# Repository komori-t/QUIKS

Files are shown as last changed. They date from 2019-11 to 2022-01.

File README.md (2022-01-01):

# QUIKS


QUIKS unifies inexpensive kinetic sensors

## About

QUIKS is an inexpensive motion tracking system.

It is consists of one terminal node and multiple sensor nodes.

Each node has a sensor and the terminal node bridges PC and them.



## QUIKS is ...

### 1. Inexpensive

QUIKS is designed to construct motion tracking system at low cost.

### 2. Extendable

New node can be added by just connecting to RS485 bus.

It is easy to develop new kind of node to extend the system.

### 3. Scalable

More nodes you connect, more data you get.

So you can omit any nodes to reduce costs, areas, times, etc.

If you do not need to track the lower half of your body, you can only upper half nodes for example.

## Currently available node

### IMUTracker

The IMUTracker is a kind of node that captures rotation of one bone.

It has IMU sensor ICM20948 controlled by a tiny microcontroller LPC802.

### USB terminal node

USB terminal node is a kind of terminal node that communicates with PC through USB.

It acts as virtual serial port and bridges USB and RS485 bus.

IMUTracker and USB terminal node shares the same design of circuit to reduce manufacturing costs.

## Other nodes to be added (hopefully)

### Wireless terminal node

Wireless terminal node is a kind of teminal node that communicates with PC wirelessly (maybe in 900 MHz band).

### Absolute position tracking node

If the position of one bone (typically waist) can be detected, it is possible to move around in virtual world.

## Documentation

A technical memo (in the form of paper) of IMUTracker can be found [here](https://gist.github.com/komori-t/2a9c5ed3c2d6123b80474edbda02dfcf/raw/6774a583ee427da89996ef7d9e91693c2fbc6523/imutracker.pdf).

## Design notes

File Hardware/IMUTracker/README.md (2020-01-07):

# IMUTracker
hardware_abst_image

## Design and connectivity
IMUTracker system is consisted of two different designs, Base and Single. Both uses same IMUTracker sensor on it, also Base uses MicroUSB to RS485 convertor as well. The Base have micro usb port, and entire QUIKS will be connected to PC through this port.

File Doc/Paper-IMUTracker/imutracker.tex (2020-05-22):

%! TEX program = pdflatex
\documentclass[journal]{IEEEtran}
\usepackage{siunitx}
\usepackage{amsmath}
\usepackage{amssymb}
\usepackage{bm}
\usepackage[table,xcdraw]{xcolor}
\usepackage[pdftex]{graphicx}

\DeclareGraphicsRule{.ai}{pdf}{.ai}{}

\begin{document}

\title{QUIKS: an inexpensive motion tracking system}
\author{}
\maketitle
\begin{abstract}
Reducing cost for motion tracking system is essential for better virtual reality (VR) experience.
In this paper, we describe our low-cost system named QUIKS.
It is optimized for VR usage only.
Therefore, it can be constructed of inexpensive parts such as IMU and Cortex-M0+ MCU.
In addition, sensors not only sample motions but also calculate offset and apply transformation.
This lowers CPU usage of host PC.
We only spent about 10 dollars for tracking one joint.
In out tests, laptop PC without GPU can perform motion traccking and 3DCG rendering for 30 fps.
The quality and latency of motion is sufficient for VR experience.
\end{abstract}

\section{Introduction}
To capture the movement of a user is essential for the virtual reality (VR) experience.
With the increase of the number of VR user (including game player, streamer, etc.), perchasing motion tracking devices such as Vive tracker or Perception Neuron is thought to be a common case.
However, these products are still expensive and only a few user can perchase them.
Thus, a low-cost motion tracking system which is suitable for VR usage is needed.
Such a device should not track a motion much precisely or quickly.
That is, it is not suitable for the tasks like measurements and only produce 30 or 60 samples per second.
Also, it cannot be used with some particular motions which are difficult to track.

\section{Basis of motion tracking}
\subsection{Target software}
A motion data measured by a sensor is sent to some software to produce CG images for a user.
In this paper, we target Unity for that role because we can use it for free with few limitations.
However, most of our system can be reused for other software.

\subsection{Tracking method}
There are roughly two methods to track motions.
One is an optical method.
It can track almost every motions very precisely with low latency.
However, it needs multiple cameras and lots of calculation resources.
Thus, this method is not suitable for an inexpensive system.

The another is an inertial method.
It cannot track the absolute position of a body, but it is simple and costs less.
Therefore, we adopt this method.

The inertial method captures joint rotations and just assign them to a 3D model.
3DCG engine like Unity manages its internal model movements by rotations.
In general, inertial motion tracking can be achieved with following steps.
\begin{enumerate}
    \item Measure joint rotations by inertial measurement unit(IMU).
    \item Convert measured data for a 3DCG software.
    \item Assign joint rotations to a 3D model.
\end{enumerate}

\subsection{Quaternion}
A rotation in 3D space can be represented as the form of quaternion.
In this paper, we define a quaternion \(\bm{q}\) as (\ref{quat-def}).
\begin{equation}
    \bm{q} \overset{\mathrm{def}}{=} w + \mathbf{i}x + \mathbf{j}y + \mathbf{k}z = w + \begin{pmatrix}
        x \\
        y \\
        z
    \end{pmatrix} \label{quat-def}
\end{equation}
where \(w\) is the real part of a quaternion and \(x,\,y,\,z\) are the imaginary part.
\begin{table}[tb]
    \centering
    \caption{Quaternion multiplication} \label{quat-mult}
    \begin{tabular}{ccccc}
    \rowcolor[HTML]{9B9B9B} 
                                           & 1              & \(\mathbf{i}\)  & \(\mathbf{j}\)  & \(\mathbf{k}\)  \\
    \cellcolor[HTML]{9B9B9B}1              & \(1\)          & \(\mathbf{i}\)  & \(\mathbf{j}\)  & \(\mathbf{k}\)  \\
    \rowcolor[HTML]{EFEFEF} 
    \cellcolor[HTML]{9B9B9B}\(\mathbf{i}\) & \(\mathbf{i}\) & \(-1\)          & \(\mathbf{k}\)  & \(-\mathbf{j}\) \\
    \cellcolor[HTML]{9B9B9B}\(\mathbf{j}\) & \(\mathbf{j}\) & -\(\mathbf{k}\) & \(-1\)          & \(\mathbf{i}\)  \\
    \rowcolor[HTML]{EFEFEF} 
    \cellcolor[HTML]{9B9B9B}\(\mathbf{k}\) & \(\mathbf{k}\) & \(\mathbf{j}\)  & \(-\mathbf{i}\) & \(-1\)         
    \end{tabular}
\end{table}
Multiplication between each parts are defined as Table \ref{quat-mult}.
Also, (\ref{quat-norm}) always have to be valid.
When a quaternion holds this condition, it is called to be normalized.
\begin{equation}
    |\bm{q}| \overset{\mathrm{def}}{=} \sqrt{w^2 + x^2 + y^2 + z^2} = 1 \label{quat-norm} 
\end{equation}
Sometimes we need the inverse (or complementary) quaternion \(\bm{q}^{-1}\) defined as (\ref{quat-inv})
\begin{equation}
    \bm{q}^{-1} \overset{\mathrm{def}}{=} \frac{w - \mathbf{i}x - \mathbf{j}y - \mathbf{k}z}{w^2 + x^2 + y^2 + z^2} = w - \mathbf{i}x - \mathbf{j}y - \mathbf{k}z \label{quat-inv}
\end{equation}

The rotation around the axis \(\bm{u} = (u_x,\,u_y,\,u_z)^\mathrm{T}\in\mathbb{R}^3\) by angle \(\theta\) can be expressed in (\ref{quat-rot}).
\begin{equation}
    \bm{q} = \cos\left(\frac{\theta}{2}\right) + \begin{pmatrix}
        u_x \\
        u_y \\
        u_z
    \end{pmatrix} \sin\left(\frac{\theta}{2}\right) \label{quat-rot}
\end{equation}
where \(|\bm{u}| = 1\).

The rotaion \(\bm{q}_2\bm{q}_1\) means the rotation applying \(\bm{q}_1\), then \(\bm{q}_2\).

Real world coordinate and 3DCG engine coordinate are often different.
Real world is represented as left-handed coordinate system and Unity uses right-handed one for example.
In this case, we should convert rotation axis \(\bm{u}\) to \(\bm{u}'\) with \(\bm{u}' = A\bm{u}\) where \(A\in\mathbb{R}^{3\times 3}\) is an transformation matrix.
Therefore, a quaternion \(\bm{q}\) can be converted to \(\bm{q}'\) by (\ref{quat-conv}).
\begin{equation}
    \bm{q}' = w + A\begin{pmatrix}
        x \\
        y \\
        z
    \end{pmatrix} \label{quat-conv}
\end{equation}

\section{Our system}
\subsection{Overview}
Figure \ref{block} shows the block diagram of our system, QUIKS.
\begin{figure}[tb]
    \centering
    
    \caption{Block diagram of QUIKS} \label{block}
\end{figure}
QUIKS is consists of multiple sensor nodes and a terminal node.
Each sensor node have an IMU and measures rotation of a joint.
The terminal node bridges PC and sensor nodes by converting USB and RS485 communication.
Basically, PC sends requests to each node and sensors return quaternions.
Every sensor node has a unique ID, which enables PC to communicate sensors separately.

\subsection{Electronic}
Sensor node is mainly consists of an IMU, a microcontroller unit(MCU), and an RS485 transceiver as shown in Figure \ref{circuit}.
\begin{figure}[tb]
    \centering
    
    \caption{Block diagram of sensor node} \label{circuit}
\end{figure}
We use ICM20948 from invensense for IMU.
This sensor provides Digital Motion Processing(DMP) function which enables a sensor to calculate imaginary parts of a quaternion from raw sensor values.
With this capability, we do not need to care about raw sensor value issues such as offset, drift, or random noise.
Therefore, our system can be built with a tiny software and we can reduce costs for MCU.
Measurement data quality is also guaranteed to be relatively good.

We use LPC802 from NXP for MCU.
This is the cheapest 32-bit MCU provided by NXP and one of the most cost-efficient ARM processor in the market.
The calculation resource of this MCU is limited, but it is enough to handle both the communicaton with PC and IMU.
Also, it offers great low-power capability which enables both the IMU and MCU be powered with small \SI{1.8}{\V} regulator.
The switch-matrix functionality of LPC802 makes wiring design easy and keep board size small.
And most importantly, it has ARM Cortex-M0+ core configured with some essential features like fast multiplication, software reset, and vector table offsetting.

Baud rate of RS-485 bus is \SI{460800}{bps} because the transciever IC supports up to \SI{500}{kbps}.
A UART packet is consists of 1 start bit, 8 bit data, and 1 stop bit.
Therefore, effective communication rate is \(\SI{460800}{bps} \times 8/10 = \SI{368640}{bps}\).

The quaternion request and return requires 80 bytes of payload, that is, 10 UART packets.
Thus, the number of quaternion transportable in every second is \(\SI{368640}{bps} / 80 = \num{4608}\).
If the frame rate is 30 fps, \(\num{4608} / 30 \sim 153\) quaternions can be handled in every frame.
This speed is enough to achieve full-body tracking.

\subsection{Software}
We developed software for sensor node and Unity.

Sensor node program is written in C and a few assembly.
The code uses lots of inline expansion to reduce subroutine call latancy since the MCU is not so powerful.
We do not use any RTOS because the software is small enough and the size of ROM/RAM cannot contain RTOS kernel/stack.

Unity program is written in C\#.
It abstructs sensor nodes and assign rotation from sensors to 3D model.
Unity will handle rotations and we do not need to be involved in 3DCG processing.

\section{Embedded software specification}
\subsection{Overview}
The software for sensor node boots with a bootloader, which provides a way to recover main program, then the bootloader branches to the main program.

\subsection{Bootloader}
The bootloader is the program which is launched firstly.
Figure \ref{boot-act} shows the activity diagram of it.
\begin{figure}[tb]
    \centering
    
    \caption{Activity diagram of the bootloader} \label{boot-act}
\end{figure}
It initializes some hardware and waits a magic packet for \SI{2}{seconds}.
If no packet is detected (normal case), it sets the interrupt vector and branches to the main program.

Firmware update sequence is performed as shown in Figure \ref{boot-upd}
\begin{figure}[tb]
    \centering
    
    \caption{Firmware update sequence} \label{boot-upd}
\end{figure}
Update is performed for each \SI{64}{kB} flash pages.
PC sends a page of program and the sensor saves it in RAM.
Then, it sends the program back to the PC.
So PC side can validate whether the program is correctly sent or not.
If an error is detected, PC sends NG to the sensor and sends the same page again.
After all the program is flashed, the sensor will reboot and update finishes.

This update sequence still has a risk to flash a wrong program.
Clearly, it is impossible to \SI{100}{\percent} guarantee that the program is valid.
However, as long as the bootloader is valid, we can flash the main program again.

\subsection{Main program}
The main program is launched by the bootloader.
It obtains quaternions from the IMU, processes them suitable for Unity, then sends them to the PC.

The main program converts a quaternion \(\bm{q}_{\mathrm{IMU}}\) from the IMU to \(\bm{q}_{\mathrm{Unity}}\) for Unity as shown in (\ref{qconv}).
\begin{equation}
    \bm{q}_{\mathrm{Unity}} = T(\bm{q}_{\mathrm{IMUoffset}}\bm{q}_{\mathrm{IMU}})\bm{q}_{\mathrm{Unityoffset}} \label{qconv}
\end{equation}
Where \(T(\bm{q})\) represents the conversion between coordinates.

\(\bm{q}_{\mathrm{IMUoffset}}\) and \(\bm{q}_{\mathrm{Unityoffset}}\) are the offset rotations.
A user should first strike the same pose as 3D model, then initialize offsets as \(\bm{q}_{\mathrm{IMUoffset}} = {\bm{q}_{\mathrm{IMU}}}^{-1}\) and \(\bm{q}_{\mathrm{Unityoffset}} = \bm{q}_{\mathrm{Unity}}\).

\subsection{Real part of a quaternion}
ICM20948, the IMU we use, produces only imaginary part of a quaternion.
Therefore, we must calculate a real part in some way.
Since normalized quaternion holds (\ref{quat-norm}), \(w\) can be obtained through (\ref{quat-w}).
\begin{equation}
    w = \pm\sqrt{1 - x^2 - y^2 - z^2} \overset{\mathrm{def}}{=} \pm w_0 \label{quat-w}
\end{equation}
The problem is which sign should be used.
In short, both signs are fine.
From (\ref{quat-rot}), we can obtain (\ref{quat-wcos}).
\begin{equation}
    w = \cos\left(\frac{\theta}{2}\right) \label{quat-wcos}
\end{equation}
Therefore, \(\theta\) can be expressed as (\ref{quat-theta}).
\begin{align}
    \theta &= 2\cos^{-1}(w) = \begin{cases}
        2\cos^{-1}(w) & (w = w_0) \\
        2\pi - 2\cos^{-1}(-w) & (w = -w_0)
    \end{cases} \notag \\
    &= \pm 2\cos^{-1}(|w|) \label{quat-theta}
\end{align}
Thus, the final representation of \(\bm{q}\) becomes (\ref{quat-pmq}).
\begin{equation}
    \bm{q} = w + \bm{u}\sin\{\pm 2\cos^{-1}(|w|)\} = \pm w_0 \pm \bm{u}\sin(|\theta|) \label{quat-pmq}
\end{equation}
This means inverting \(w\) also inverts \(\theta\) and \(\bm{u}\).
Both rotations are clearly the same.
You can also validate this by checking the identity \(qq'^{-1} \equiv q^{-1}q' \equiv 1\) where the real part of \(q'\) is the negative of the one of \(q\).

\subsection{Fixed-point number}
ICM20948 represents real number as Q30, fixed-pont number.
In general, Q\(n\) means a fixed-point number point where fractional part has \(n\) bits.
Therefore, Q30 can represent the range \([-1:1)\).

In this paper, we express a Q30 number \(n\) as (\ref{q30-def}).
\begin{equation}
    n = 2^{-30}N \label{q30-def}
\end{equation}
Where \(N\) is the 32-bit integer representation of \(n\).
Since CPU can only handle \(N\), we must be careful about relationship between the two representations.

\subsubsection{Algebra}
In order to complete quaternion calculation (\ref{qconv}) and (\ref{quat-w}), we must define Q30 addition, subtraction, multiplication, square root.
Addition and subtraction are easily done with (\ref{q30-add}).
\begin{equation}
    n_1 \pm n_2 = 2^{-30}N_1 \pm 2^{-30}N_2 = 2^{-30}(N_1 \pm N_2) \label{q30-add}
\end{equation}
This means addition or subtraction in 32-bit integer representation can calculate the same operation in Q30 directly.

Q30 multiplication can be done as shown in (\ref{q30-mult}).
\begin{equation}
    n_1 n_2 = 2^{30}(2^{-30}N_12^{-30}N_2) = 2^{-30}N_1N_2 \label{q30-mult}
\end{equation}
This means multiplication can be done through shifting 32-bit integer product by 30 bits.
However, Cortex-M0+ core can only calculate lower 32 bits of a product efficiently.
Thus, we must transform the expression to achieve a good performance.

The easiest method can be expressed as (\ref{q30-fastmul}).
\begin{equation}
    n_1n_2 = \left(2^{-15}N_1\right)\left(2^{-15}N_2\right) \label{q30-fastmul}
\end{equation}
This implementation is very fast, but accuracy is only about the order of \(2^{14} \sim 10^{-4.2}\) in our test.

A more accurate method is based on the fact that multiplication of two 16-bit integers results a 32-bit product.
Thus, we can separate the whole multiplication into the four.
In order to do this, we define two 16-bit number \(N_{\mathrm{u}}\) and \(N_{\mathrm{l}}\) as shown in (\ref{q30-ul}).
\begin{equation}
    N \overset{\mathrm{def}}{=} 2^{16}N_{\mathrm{u}} + N_{\mathrm{l}} \label{q30-ul}
\end{equation}
Such that \(N_{\mathrm{u}}\) represents the upper 16-bit of \(N\) and \(N_{\mathrm{l}}\) represents lower.
Then, we define the Q30 multiplication as shown in (\ref{q30-mult2}).
\begin{align}
    n_1&n_2 = 2^{-30}\left(2^{16}N_{\mathrm{1u}} + N_{\mathrm{1l}}\right)\left(2^{16}N_{\mathrm{2u}} + N_{\mathrm{2l}}\right) \notag \\
    &= 2^2N_{\mathrm{1u}}N_{\mathrm{2u}} + 2^{-14}(N_{\mathrm{1u}}N_{\mathrm{2l}} + N_{\mathrm{1l}}N_{\mathrm{2u}}) + 2^{-30}N_{\mathrm{1l}}N_{\mathrm{2l}} \label{q30-mult2}
\end{align}
The accuracy of this method is about the order of \(2^{-27} \sim 10^{-8.1}\) in our test.
Clearly, the last part of the product shifted right by 30 bits is useless.
After emitthing this, we can obtain (\ref{q30-mult3}).
\begin{equation}
    n_1n_2 = 2^{2}N_{\mathrm{1u}}N_{\mathrm{2u}} + 2^{-14}(N_{\mathrm{1u}}N_{\mathrm{2l}} + N_{\mathrm{1l}}N_{\mathrm{2u}}) \label{q30-mult3}
\end{equation}

\subsubsection{Square root}
Square root can be generally obtained using Newton's method.
However, it needs Q30 division which cannot be executed fastly.
Therefore, we use taylor series for calculating Q30 square root.

According to the taylor's theorem, the \(k + 1\) differentiable function \(f(x)\) can be represented as (\ref{taylor}) around \(a\).
\begin{equation}
    f(x) = \sum_{n=0}^{k} \left.\frac{\mathrm{d}^n f}{{\mathrm{d}x}^n}\right|_{x=a}\frac{(x - a)^n}{n!} + R_{k+1}(x) \label{taylor}
\end{equation}
The remainder \(R_{n}(x)\) has a value of (\ref{remainder}).
\begin{equation}
     R_{n}(x) = \left.\frac{\mathrm{d}^n f}{{\mathrm{d}x}^n}\right|_{x=c}\frac{(x - a)^n}{n!} \label{remainder}
\end{equation}
where \(c\) is a real number between \(a\) and \(x\).
We use 4th ordered taylor series shown in (\ref{root-taylor}) and (\ref{r5}).
\begin{equation}
    \sqrt{x} = \sqrt{a} + \frac{x - a}{2\sqrt{a}} - \frac{(x - a)^2}{8a^{3/2}} + \frac{(x - a)^3}{16a^{5/2}} - \frac{5(x-a)^4}{128a^{7/2}} + R_{5}(x) \label{root-taylor}
\end{equation}
\begin{equation}
    R_5(x) = \frac{7(x-a)^5}{256c^{9/2}} \label{r5}
\end{equation}

(\ref{r5}) indicates that the distance between \(x\) and \(a\) induces the error.
Thus, it is essential to make \(x\) close to \(a\).
To achieve this, we can use an identity (\ref{root-shift}).
\begin{equation}
    \sqrt{x} \equiv 2^{-n/2}\sqrt{2^n x} \label{root-shift}
\end{equation}

Recalling that multiplying power of 2 is equivalent to bit shift, we can move a most significant set bit to a specific position.
If the most significant set bit of a Q30 number \(x\) is the bit 29, \(0.5 \leq x < 1.0\) holds.
A limitation of this method is \(n\) must be an even number bacause \(n/2\) is needed.

To shift the most significant set bit, we must know the number of clear bits from MSB.
This operation is called count-leading-zeros(CLZ).
In this paper, we define it as a function \(\operatorname{CLZ}(x)\).
\(\operatorname{CLZ}(\mathrm{0x0800000}) = 8\) for example.
\(n\) can be obrained using CLZ as shown in (\ref{nbycases}).
\begin{equation}
    n = \begin{cases}
        \operatorname{CLZ}(x) - 3 & (\operatorname{CLZ}(x)\operatorname{mod}2 = 1) \\
        \operatorname{CLZ}(x) - 2 & (\operatorname{CLZ}(x)\operatorname{mod}2 = 0)
    \end{cases} \label{nbycases}
\end{equation}
Then, the condition \(0.25 \leq 2^nx < 0.5\) or \(0.5 \leq 2^nx < 1.0\) holds.

\(a\) is chosen for different conditions to minimize the maximum error.
That is, the optimum value \(\hat{a}\) satisfies (\ref{ahat}) is chosen.
\begin{equation}
    \hat{a} = \underset{a}{\operatorname{argmin}}\;\underset{x}{\operatorname{max}}\;R_5(x) \label{ahat}
\end{equation}
We obtained 0.3685 and 0.737 for \(\hat{a}\) numerically.

\section{Testing results}
We connected 9 sensors to track both shoulders, elbows, hips, knees, and spine.
Host PC is MacBook Air 2019 model equipped with Dual-Core Intel Core i5 running at \SI{1.6}{\GHz} and RAM of \SI{16}{GB}.

\begin{figure}[tb]
    \centering
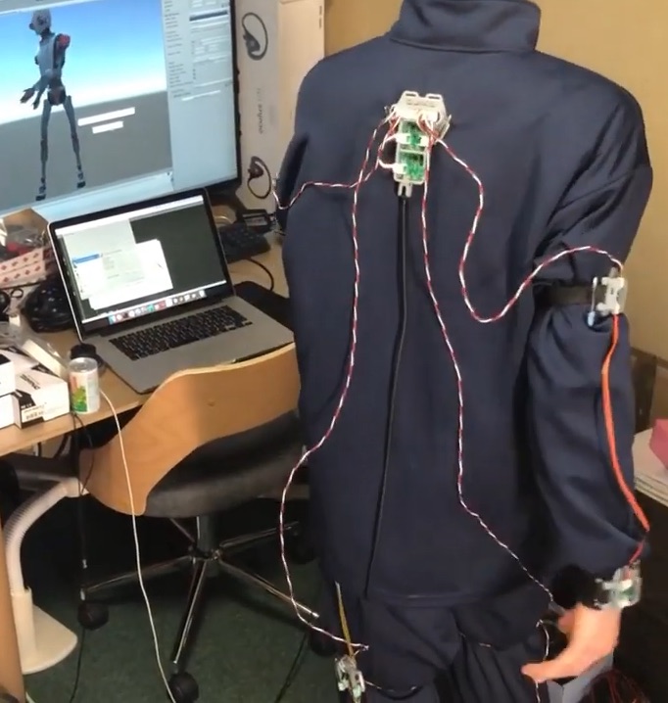
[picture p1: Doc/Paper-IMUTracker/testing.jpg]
    
    \caption{Testing scene} \label{testing}
\end{figure}
Figure \ref{testing} shows the scene of testing.
It can be seen that 3D model in the display reflects the pose of the user.
CPU usage is about \SI{20}{\percent}.

\section{Conclusion}
We propose a low-cost motion tracking system optimized for VR experience.
It only spends about 10 dollars per joint and produces 30 samples per second.
The accuracy is enough to reflect real-world movements.

Our future work is to evaluate the system quantitatively.
Developing other nodes such as wireless terminal node or position tracking node is also our future work.

\appendix
Table \ref{list} lists components of sensor node and terminal node.
The price is in USD and if you order multiple units at once, prices can be lowered.

\begin{table*}[t]
    \centering
    \caption{Component list} \label{list}
    \begin{tabular}{cccc}
        \hline
        Part & Vendor & Model & Unit Price \\ \hline
        MCU & NXP & LPC802M001JDH16FP & \$1.29 \\
        IMU & TDK & ICM-20948 & \$8.04 \\
        Regulator & Microchip & MIC5504-1.8YM5-TR & \$0.11 \\
        RS-485 Transceiver & TI & THVD1500DR & \$1.51 \\
        USB to UART Interface & FTDI & FT234XD & \$2.04 \\
        \hline
    \end{tabular}
\end{table*}

\end{document}

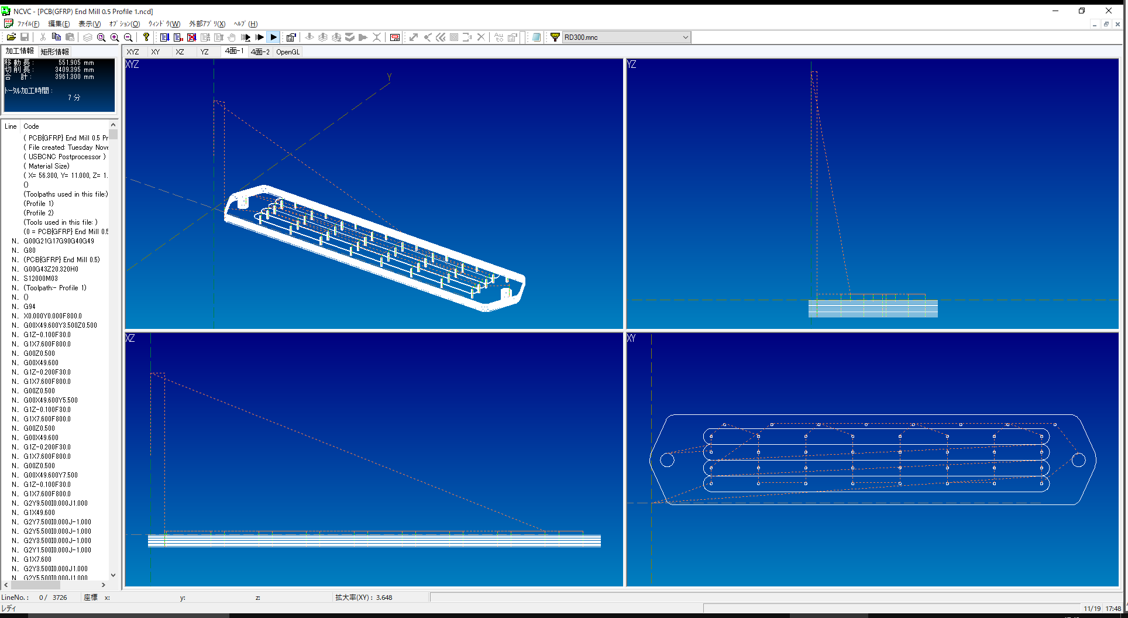
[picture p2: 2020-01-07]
Hardware/IMUTracker/Casing/Base/BASE_HUB_PCB/CNC/PCB(GFRP) End Mill 0.5 Profile 1.png

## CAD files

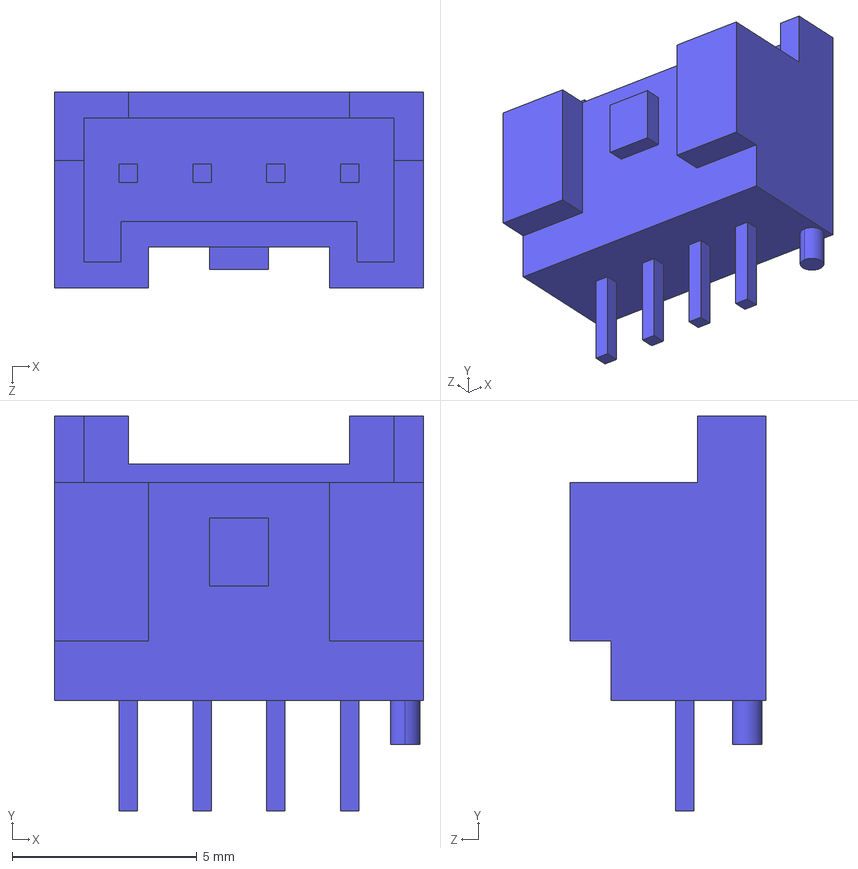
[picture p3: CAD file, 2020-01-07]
Hardware/IMUTracker/Casing/Base/BASE_HUB_PCB/B04B-PASK-1.STEP
10.0 x 10.7 x 5.30 mm

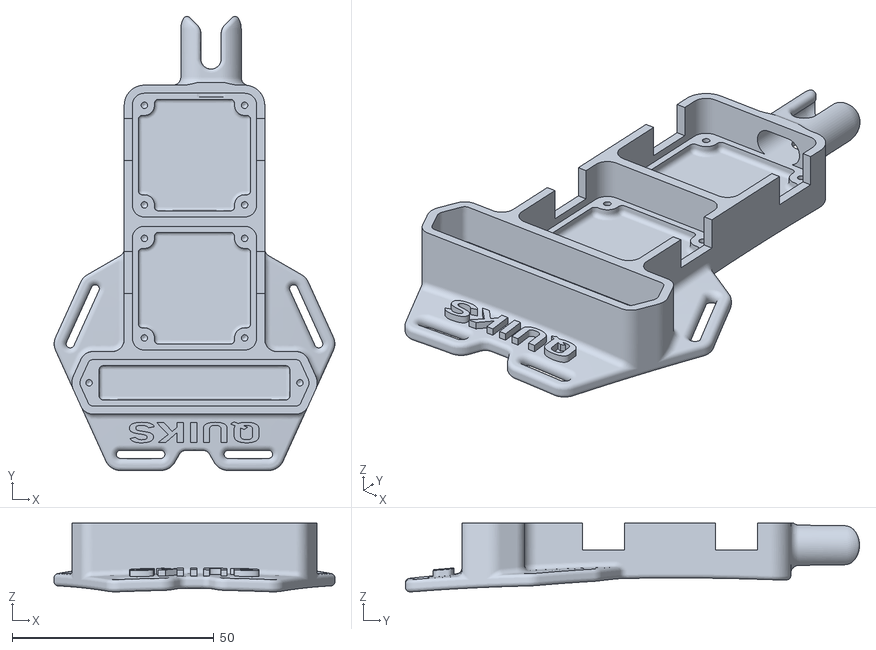
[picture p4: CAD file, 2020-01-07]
Hardware/IMUTracker/Casing/Base/STL/IMUTrackerBaseFrame.stl
69.6 x 112.6 x 17.0

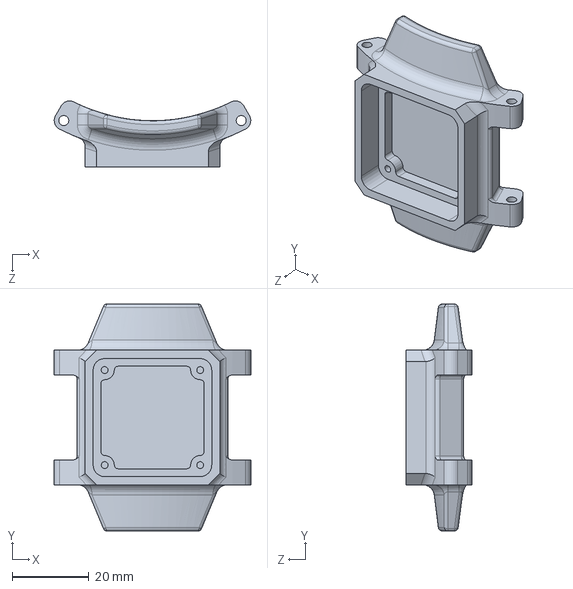
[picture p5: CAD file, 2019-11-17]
Hardware/IMUTracker/Casing/Single/IMUTracker_casing_v1.SLDPRT
51.1 x 59.0 x 17.2 mm

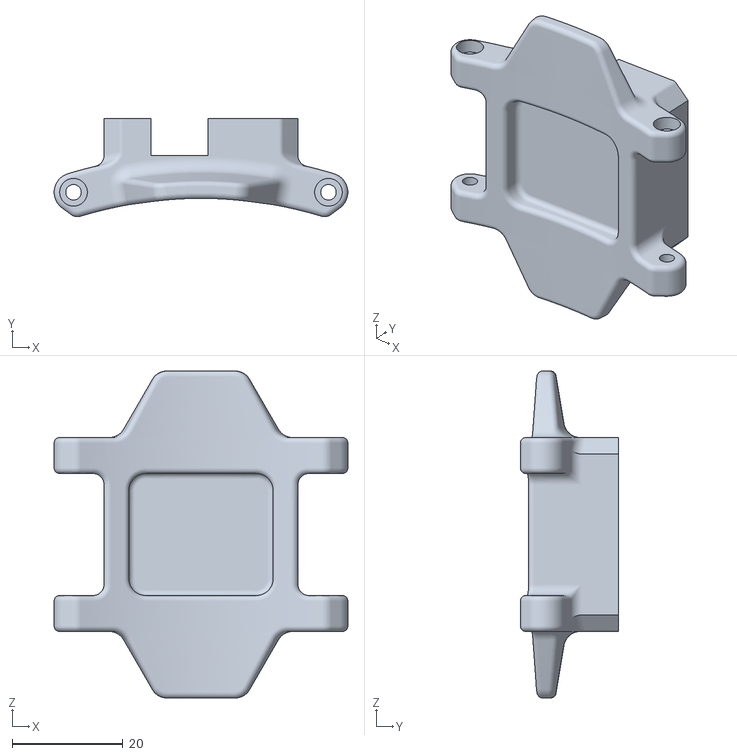
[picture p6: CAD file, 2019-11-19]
Hardware/IMUTracker/Casing/Single/STL/casing_v2/IMUTracker_casing_v2.stl
53.0 x 17.7 x 59.0

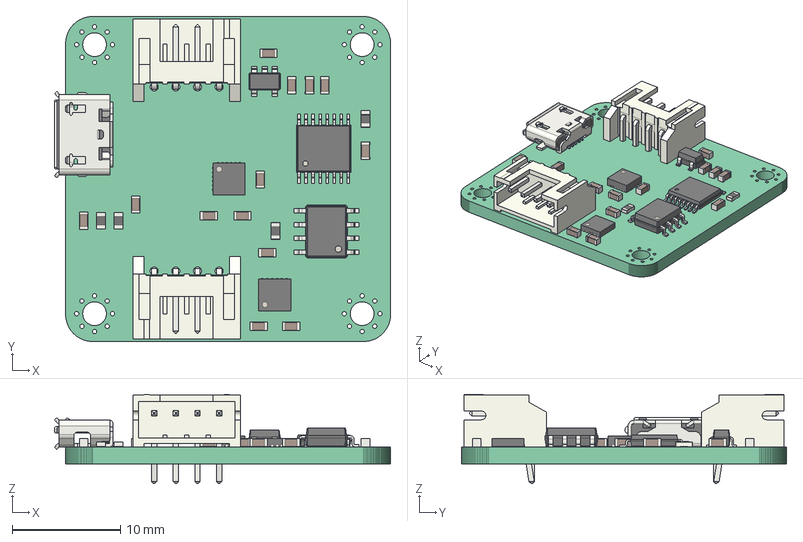
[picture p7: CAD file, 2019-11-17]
Hardware/IMUTracker/Circuit/IMUTracker.step
31.0 x 30.0 x 8.25 mm
Pcb
PCB_Sketch
C11_C_0603_5C47C8DF
U2_TSSOP_16_44x5mm_Pitch065mm_5C47CB0E
C1_C_0603_5C47C846
C2_C_0603_5C47C857
C3_C_0603_5C47C868
C4_C_0603_5C47C879
C6_C_0603_5C47C88A
C7_C_0603_5C47C89B
C8_C_0603_5C47C8AC
C9_C_0603_5C47C8BD
C10_C_0603_5C47C8CE
C12_C_0603_5C47C8F0
D1_C_0603_5C47C905
R1_R_0603_5C47CAA6
R2_R_0603_5C47CAB7
R3_R_0603_5C47CAC8
R4_R_0603_5C47CAD9
U1_SOT_23_5_5C47CAEE
U3_DFN-12-1EP_3x3mm_Pitch0.45mm_5C47CB2D
U4_SOIC-8_3.9x4.9mm_Pitch1.27mm_5C47CB4A
U5_QFN-24-1EP_3x3mm_Pitch0.4mm_5C47CB7A
C5_C_0603_5C47D793
J5_S04B_PH_K_5C57E076
J6_S04B_PH_K_5C57E0A6
J4_USB_Micro-B_Molex_47346-0001_5C544C86

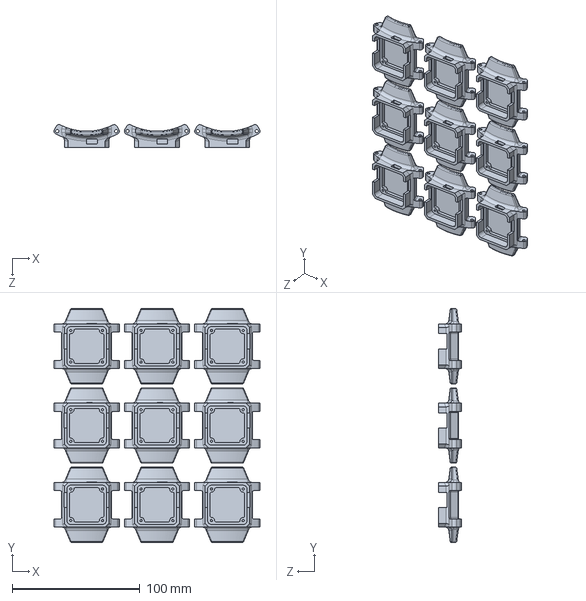
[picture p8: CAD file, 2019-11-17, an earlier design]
Hardware/IMUTracker/Casing/Single/STL/casing_v1/ARRAY_4x3.SLDASM
161.1 x 183.0 x 17.8 mm
Housing x 9

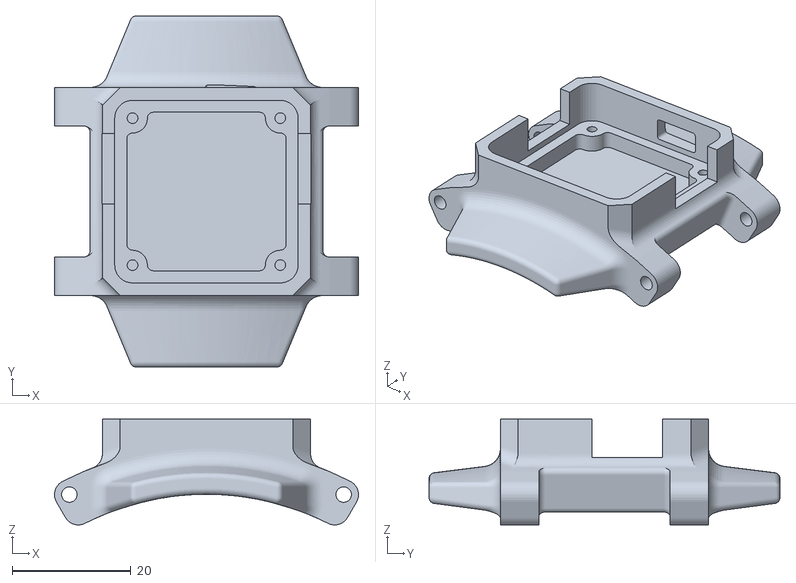
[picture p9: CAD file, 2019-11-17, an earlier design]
Hardware/IMUTracker/Casing/Single/STL/casing_v1/Housing.STL
51.1 x 59.0 x 17.8

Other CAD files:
Hardware/IMUTrackerBase/BASE_HUB_PCB/IMUTrackerBase_8port_hub_pcb.dwg
Hardware/IMUTracker/Casing/Base/BASE_HUB_PCB/IMUTrackerBase_8port_hub_pcb.dwg
Hardware/IMUTracker/Casing/Base/BASE_HUB_PCB/IMUTrackerBase_8port_hub_asm.iam
Hardware/IMUTracker/Casing/Base/BASE_HUB_PCB/IMUTrackerBase_8port_hub_pcb.ipt
Hardware/IMUTracker/Casing/Base/IMUTrackerBaseFrame.ipt
Hardware/IMUTracker/Casing/Single/AR-2622.ipt
Hardware/IMUTracker/Casing/Single/C-2003-4.ipt
Hardware/IMUTracker/Casing/Single/IMUTracker_assemble.iam
Hardware/IMUTracker/Casing/Single/IMUTracker_casing_v2.ipt
Hardware/IMUTracker/Casing/Single/QUIKS_SINGLE_COVER.ipt
Hardware/IMUTracker/Circuit/IMUTracker_Inveotor_model/Board_Geoms.iam
Hardware/IMUTracker/Circuit/IMUTracker_Inveotor_model/C10_C_0603_5C47C8CE.ipt
Hardware/IMUTracker/Circuit/IMUTracker_Inveotor_model/C11_C_0603_5C47C8DF.ipt
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

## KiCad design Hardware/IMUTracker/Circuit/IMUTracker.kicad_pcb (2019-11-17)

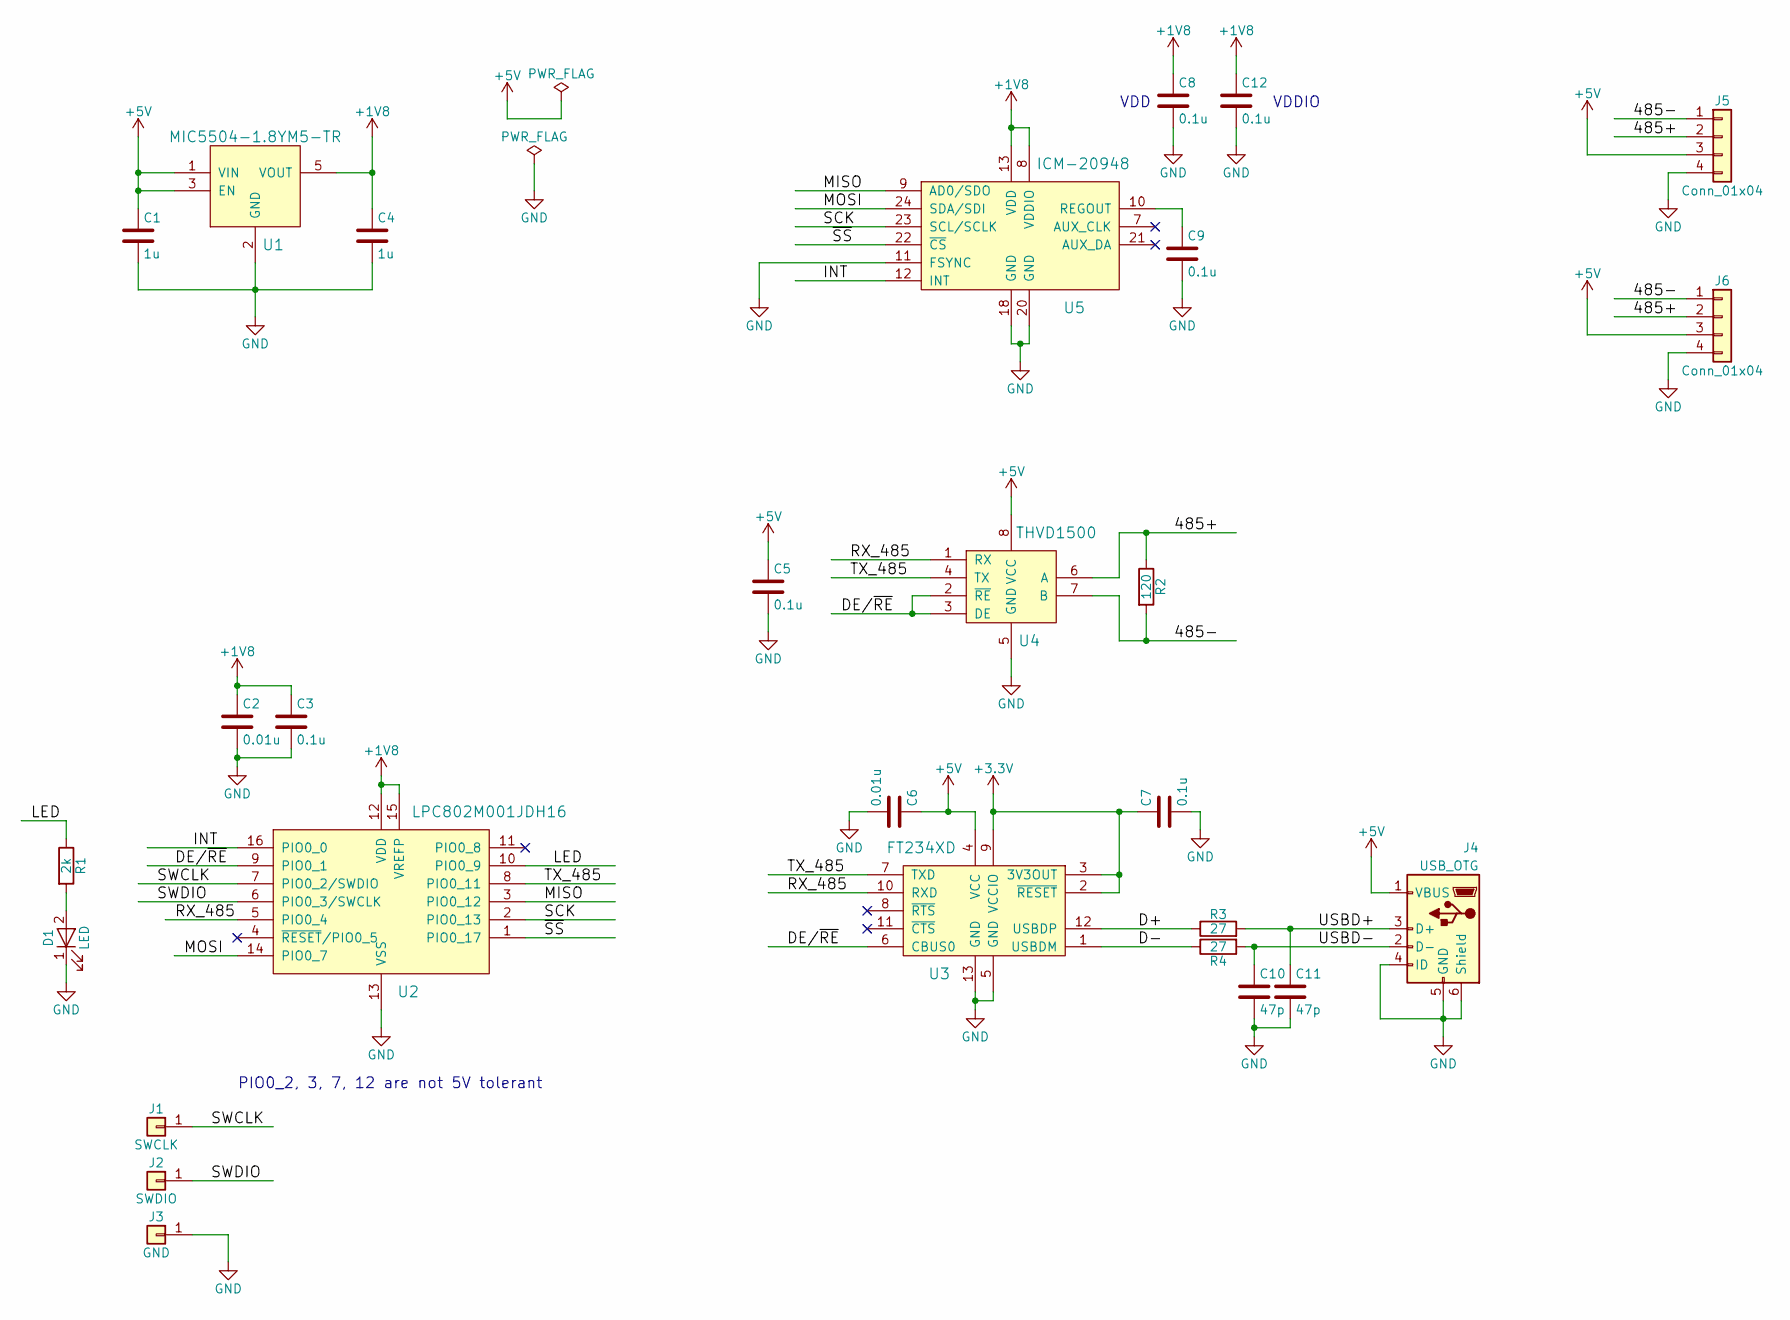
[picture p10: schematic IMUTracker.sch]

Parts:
C1, C4: 1u; C_0603
C2, C6: 0.01u; C_0603
C3, C5, C7, C8, C9, C12: 0.1u; C_0603
C10, C11: 47p; C_0603
D1: LED; LED_0603
J1: SWCLK; Measurement_Point_Round-SMD-Pad_Small
J2: SWDIO; Measurement_Point_Round-SMD-Pad_Small
J3: GND; Measurement_Point_Round-SMD-Pad_Small
J4: USB_OTG; ZX62-B-5PA
J5, J6: Conn_01x04; JST_PA_04_Angled
R1: 2k; R_0603
R2: 120; R_0603
R3, R4: 27; R_0603
U1: MIC5504-1.8YM5-TR; SOT-23-5
U2: LPC802M001JDH16; TSSOP-16_4.4x5mm_Pitch0.65mm
U3: FT234XD; DFN-12-1EP_3x3mm_Pitch0.45mm
U4: THVD1500; SOIC-8_3.9x4.9mm_Pitch1.27mm
U5: ICM-20948; ICM20948

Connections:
+1V8: C2.1, C3.1, C4.1, C8.1, C12.1, U1.5 (VOUT), U2.12 (VDD), U2.15 (VREFP), U5.8 (VDDIO), U5.13 (VDD)
+3V3: C7.1, U3.2 (~RESET), U3.3 (3V3OUT), U3.9 (VCCIO)
+5V: C1.1, C5.1, C6.1, J4.1 (VBUS), J5.3, J6.3, U1.1 (VIN), U1.3 (EN), U3.4 (VCC), U4.8 (VCC)
/485+: J5.2, J6.2, R2.1, U4.6 (A)
/485-: J5.1, J6.1, R2.2, U4.7 (B)
/D+: R3.1, U3.12 (USBDP)
/D-: R4.1, U3.1 (USBDM)
/DE/~RE: U2.9 (PIO0_1), U3.6 (CBUS0), U4.2 (~RE), U4.3 (DE)
/INT: U2.16 (PIO0_0), U5.12 (INT)
/LED: R1.1, U2.10 (PIO0_9)
/MISO: U2.3 (PIO0_12), U5.9 (AD0/SDO)
/MOSI: U2.14 (PIO0_7), U5.24 (SDA/SDI)
/RX_485: U2.5 (PIO0_4), U3.10 (RXD), U4.1 (RX)
/SCK: U2.2 (PIO0_13), U5.23 (SCL/SCLK)
/SWCLK: J1.1, U2.7 (PIO0_2/SWDIO)
/SWDIO: J2.1, U2.6 (PIO0_3/SWCLK)
/TX_485: U2.8 (PIO0_11), U3.7 (TXD), U4.4 (TX)
/USBD+: C11.1, J4.3 (D+), R3.2
/USBD-: C10.1, J4.2 (D-), R4.2
/~SS: U2.1 (PIO0_17), U5.22 (~CS)
GND: C1.2, C2.2, C3.2, C4.2, C5.2, C6.2, C7.2, C8.2, C9.2, C10.2, C11.2, C12.2, D1.1 (K), J3.1, J4.4 (ID), J4.5 (GND), J4.6 (Shield), J5.4, J6.4, U1.2 (GND), U2.13 (VSS), U3.5 (GND), U3.13 (GND), U4.5 (GND), U5.11 (FSYNC), U5.18 (GND), U5.20 (GND)
unnamed: C9.1, U5.10 (REGOUT)
unnamed: D1.2 (A), R1.2

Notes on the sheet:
VDDIO
VDD
PIO0_2, 3, 7, 12 are not 5V tolerant

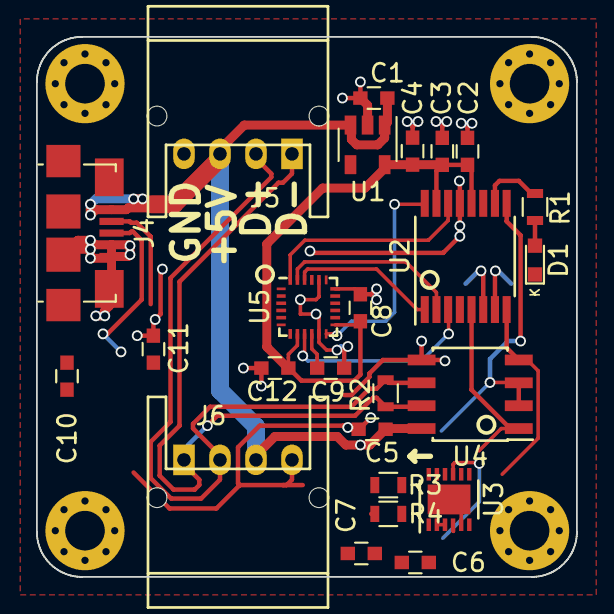
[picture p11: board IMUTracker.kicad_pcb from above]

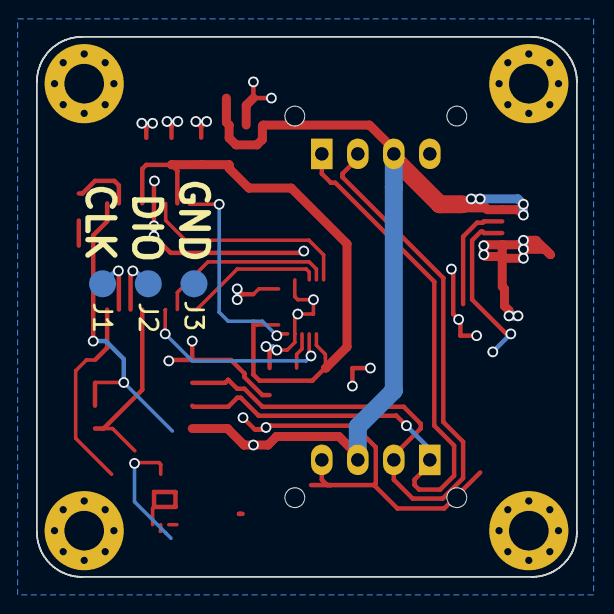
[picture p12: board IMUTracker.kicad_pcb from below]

Board: 2 copper layers, 30.0 x 30.0 mm, 28 parts (3 on the bottom side), 23 nets.

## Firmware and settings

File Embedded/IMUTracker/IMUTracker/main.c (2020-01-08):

/*
 * Copyright 2019 mtkrtk
 *
 * Licensed under the Apache License, Version 2.0 (the "License");
 * you may not use this file except in compliance with the License.
 * You may obtain a copy of the License at
 *
 *     http://www.apache.org/licenses/LICENSE-2.0
 *
 * Unless required by applicable law or agreed to in writing, software
 * distributed under the License is distributed on an "AS IS" BASIS,
 * WITHOUT WARRANTIES OR CONDITIONS OF ANY KIND, either express or implied.
 * See the License for the specific language governing permissions and
 * limitations under the License.
 */

#include <LPC8xx.h>
#include <rom_api.h>
#include "Protocol.h"
#ifndef INLINE_ALL
#include "rs485.h"
#include "spi.h"
#include "Q30.h"
#include "flash.h"
#include "ICM20948.h"
#include "Quaternion.h"
#else
#include "rs485.c"
#include "spi.c"
#include "Q30.c"
#include "Quaternion.c"
#include "flash.c"
#endif

#define ENTER_SLEEP SCB->SCR = SCB_SCR_SLEEPONEXIT_Msk; /* Enter sleep on return from ISR */ \
                    __WFI()
#define EXIT_SLEEP SCB->SCR = 0 /* Leave sleep on return from this ISR */
#define LED_ON LPC_GPIO_PORT->B0[9] = 1
#define LED_OFF LPC_GPIO_PORT->B0[9] = 0

static enum {
    state_initializing,
    state_downloading_dmp,
    state_waiting_for_header,
    state_waiting_for_id,
    state_waiting_for_command,
    state_waiting_for_unity_offset,
    state_waiting_for_axis,
    state_waiting_for_new_id,
    state_waiting_for_num_pages,
    state_replying_ack,
    state_replying_quaternion,
    state_replying_compass_accuracy,
    state_flashing,
} state = state_initializing;

static volatile int isDMPFirmwareDownloaded = 0;
static uint8_t serialBuffer[16];

static const uint8_t replyAckPacket[] = {
    PACKET_HEADER, /* ID = 0 will be automatically inserted */ Command_Reply_Ack, 1
};

static volatile struct __attribute__((packed)) {
    uint8_t dummy[2];
    uint8_t header;
    /* ID = 0 will be automatically inserted */
    uint8_t command;
    float w;
    float x;
    float y;
    float z;
} __attribute__((aligned(4))) quaternionReplyPacket = {
    .header = PACKET_HEADER, .command = Command_Reply_Quaternion,
};

static volatile struct __attribute__((packed)) {
    uint8_t header;
    /* ID = 0 will be automatically inserted */
    uint8_t command;
    uint8_t accuracy;
} replyCompassAccuracyPacket = {
    .header = PACKET_HEADER, .command = Command_Reply_Compass_Accuracy
};

static volatile quaternion_t currentChipQuaternion;
static volatile quaternion_t chipOffset = QUATERNION_INITIALIZER;
static volatile quaternion_t unityOffset = QUATERNION_INITIALIZER;

static flash_data_t __attribute__((aligned(4))) retainedData;

STATIC INLINE void replyAck()
{
    state = state_replying_ack;
    rs485_send(replyAckPacket, sizeof(replyAckPacket));
}

void PININT0_IRQHandler()
{
    LPC_PIN_INT->RISE = 1 << 0; /* Clear interrupt flag */
    EXIT_SLEEP;
}

INLINE void ICM20948_quaternion_callback(const quaternion_t *quaternion)
{
    __disable_irq();
    quaternion_copy(quaternion, (quaternion_t *)&currentChipQuaternion);
    const quaternion_t theChipOffset = QUATERNION_INIT_COPY(chipOffset);
    const quaternion_t theUnityOffset = QUATERNION_INIT_COPY(unityOffset);
    __enable_irq();
    quaternion_t chipQuat;
    quaternion_multiply(&theChipOffset, quaternion, &chipQuat);
    quaternion_t unityQuat;
    unityQuat.w.value = chipQuat.w.value;
    unityQuat.x.value = retainedData.xSign * chipQuat.axis[retainedData.xIndex].value;
    unityQuat.y.value = retainedData.ySign * chipQuat.axis[retainedData.yIndex].value;
    unityQuat.z.value = retainedData.zSign * chipQuat.axis[retainedData.zIndex].value;
    quaternion_left_mutable_multiply(&unityQuat, &theUnityOffset);
    const float ieeeW = convertQ30ToFloat(unityQuat.w.value);
    const float ieeeX = convertQ30ToFloat(unityQuat.x.value);
    const float ieeeY = convertQ30ToFloat(unityQuat.y.value);
    const float ieeeZ = convertQ30ToFloat(unityQuat.z.value);
    __disable_irq();
    quaternionReplyPacket.w = ieeeW;
    quaternionReplyPacket.x = ieeeX;
    quaternionReplyPacket.y = ieeeY;
    quaternionReplyPacket.z = ieeeZ;
    __enable_irq();
}

INLINE void ICM20948_compass_accuracy_callback(uint8_t accuracy)
{
    if (accuracy > replyCompassAccuracyPacket.accuracy) {
        replyCompassAccuracyPacket.accuracy = accuracy;
    }
    if (accuracy >= 3) {
        LED_OFF;
    }
}

#ifdef INLINE_ALL
#include "ICM20948.c"
#endif

INLINE void rs485_receive_callback()
{
    switch (state) {
        case state_downloading_dmp:
            ICM20948_rs485_callback();
            break;
            
        case state_waiting_for_header:
            if (serialBuffer[0] == PACKET_HEADER) {
                state = state_waiting_for_id;
            }
            rs485_receive(serialBuffer, 1);
            break;
            
        case state_waiting_for_id:
            if (serialBuffer[0] == DMP_UPLOAD_ID && isDMPFirmwareDownloaded == 0) {
                state = state_downloading_dmp;
                EXIT_SLEEP;
                return;
            }
            if (serialBuffer[0] == retainedData.id) {
                state = state_waiting_for_command;
                rs485_receive(serialBuffer, 1);
            } else {
                state = state_waiting_for_header;
                rs485_receive_callback();
            }
            break;
            
        case state_waiting_for_command:
            switch (serialBuffer[0]) {
                case Command_Read_Quaternion:
                    state = state_replying_quaternion;
                    rs485_send((void *)&quaternionReplyPacket.header, 18);
                    break;
                    
                case Command_Set_Unity_Offset:
                    state = state_waiting_for_unity_offset;
                    rs485_receive(serialBuffer, 16);
                    break;
                    
                case Command_Set_ID:
                    state = state_waiting_for_new_id;
                    rs485_receive((uint8_t *)&retainedData.id, 1);
                    break;
                    
                case Command_Flash:
                    state = state_flashing;
                    EXIT_SLEEP;
                    break;
                    
                case Command_Ping:
                    replyAck();
                    break;
                    
                case Command_Program:
                    state = state_waiting_for_num_pages;
                    rs485_receive(serialBuffer, 1);
                    break;
                    
                case Command_Read_Compass_Accuracy:
                    state = state_replying_compass_accuracy;
                    rs485_send((void *)&replyCompassAccuracyPacket.header, 3);
                    break;
                    
                case Command_Set_Chip_Offset:
                    quaternion_inverse((quaternion_t *)&currentChipQuaternion, (quaternion_t *)&chipOffset);
                    replyAck();
                    break;
                    
                case Command_Set_Axis:
                    state = state_waiting_for_axis;
                    rs485_receive(serialBuffer, 1);
                    break;
                    
                default:
                    state = state_waiting_for_header;
                    rs485_receive_callback();
                    break;
            }
            break;
            
        case state_waiting_for_unity_offset:
            unityOffset.w.value = ((int32_t *)serialBuffer)[0];
            unityOffset.x.value = ((int32_t *)serialBuffer)[1];
            unityOffset.y.value = ((int32_t *)serialBuffer)[2];
            unityOffset.z.value = ((int32_t *)serialBuffer)[3];
            replyAck();
            break;
            
        case state_waiting_for_axis:
            retainedData.xSign = (serialBuffer[0] & (1 << 0)) ? -1 : 1;
            retainedData.xIndex = (serialBuffer[0] >> 1) & 0b11;
            retainedData.ySign = (serialBuffer[0] & (1 << 3)) ? -1 : 1;
            retainedData.yIndex = (serialBuffer[0] >> 4) & 0b11;
            retainedData.zSign = (serialBuffer[0] & (1 << 6)) ? -1 : 1;
            retainedData.zIndex = 3 - retainedData.xIndex - retainedData.yIndex;
            replyAck();
            break;
            
        case state_waiting_for_new_id:
            replyAck();
            break;
            
        case state_waiting_for_num_pages:
            rs485_program_flash(serialBuffer[0]);
            break;
            
        default:
            break;
    }
}

INLINE void rs485_send_callback(void)
{
    switch (state) {
        case state_replying_ack:
        case state_replying_quaternion:
        case state_replying_compass_accuracy:
            state = state_waiting_for_header;
            rs485_receive(serialBuffer, 1);
            break;

        default:
            break;
    }
}

#ifdef INLINE_ALL
#include "rs485_isr.c"
#include "spi_isr.c"
#endif

int main()
{
    /* Enable peripheral clocks */
    LPC_SYSCON->SYSAHBCLKCTRL[0] |= (1 << 6)   /* GPIO */
                                  | (1 << 7)   /* switch-matrix */
                                  | (1 << 11)  /* SPI0 */
                                  | (1 << 14)  /* USART0 */
                                  | (1 << 18)  /* IOCON */
                                  | (1 << 28); /* GPIO_INT */
    LPC_SYSCON->PINTSEL[0] = 0; /* Assign P0_0 for GPIO interrupt 0 */
    LPC_SYSCON->IRQLATENCY = 0;
    
    LPC_IOCON->PIO0_9 = 1 << 7; /* LED */
    LPC_IOCON->PIO0_0 = (1 << 5) | (1 << 7); /* Disable pull-up (ICM intterrupt) */
    
    LPC_GPIO_PORT->DIRSET[0] = 1 << 9; /* Set PIO0_9 as output */
    LED_OFF;
    
    LPC_SWM->PINASSIGN[2] = (13 << 0)   /* P0_13 for SCK */
                          | (7 << 8)    /* P0_7 for MOSI */
                          | (12 << 16)  /* P0_12 for MISO */
                          | (17 << 24); /* P0_17 for SS0 */
    
    LPC_PIN_INT->IENR = 1 << 0; /* Enable interrupt for rising edge on P0_0 */
    NVIC_EnableIRQ(PININT0_IRQn);
    
    /* Disable peripheral clocks */
    LPC_SYSCON->SYSAHBCLKCTRL[0] &= ~((1 << 7)    /* switch-matrix */
                                  |   (1 << 18)); /* IOCON */
    
    flash_read(&retainedData);
    spi_init();
    ICM20948_init();
    
    state = state_waiting_for_header;
    rs485_receive(serialBuffer, 1);
    
    while (isDMPFirmwareDownloaded == 0) {
        ENTER_SLEEP;
        switch (state) {
            case state_downloading_dmp:
                ICM20948_download();
                isDMPFirmwareDownloaded = 1;
                break;
                
            case state_flashing:
                flash_write(&retainedData);
                replyAck();
                break;
                
            default:
                break;
        }
    }
    
    LED_ON;
    ICM20948_enable_dmp();
    state = state_waiting_for_header;
    rs485_receive(serialBuffer, 1);
    
    while (1) {
        ENTER_SLEEP;
        ICM20948_process_fifo();
    }

    return 0;
}

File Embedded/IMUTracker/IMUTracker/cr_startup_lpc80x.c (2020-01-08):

//*****************************************************************************
// LPC80x Microcontroller Startup code for use with MCUXpresso IDE
//
// Version : 180105
//*****************************************************************************
//
// Copyright(C) NXP Semiconductors, 2017-18
// All rights reserved.
//
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
// Permission to use, copy, modify, and distribute this software and its
// documentation is hereby granted, under NXP Semiconductors' and its
// licensor's relevant copyrights in the software, without fee, provided that it
// is used in conjunction with NXP Semiconductors microcontrollers.  This
// copyright, permission, and disclaimer notice must appear in all copies of
// this code.
//*****************************************************************************


#if defined (DEBUG)
#pragma GCC push_options
#pragma GCC optimize ("Og")
#endif // (DEBUG)

#if defined (__cplusplus)
#ifdef __REDLIB__
#error Redlib does not support C++
#else
//*****************************************************************************
//
// The entry point for the C++ library startup
//
//*****************************************************************************
extern "C" {
    extern void __libc_init_array(void);
}
#endif
#endif

#define WEAK __attribute__ ((weak))
#define ALIAS(f) __attribute__ ((weak, alias (#f)))

//*****************************************************************************
#if defined (__cplusplus)
extern "C" {
#endif

//*****************************************************************************
#if defined (__USE_CMSIS) || defined (__USE_LPCOPEN)
// Declaration of external SystemInit function
extern void SystemInit(void);
#endif

//*****************************************************************************
// Patch the AEABI integer divide functions to use MCU's romdivide library
#ifdef __USE_ROMDIVIDE
// Location in memory that holds the address of the ROM Driver table
#define PTR_ROM_DRIVER_TABLE ((unsigned int *)(0x0F001FF8))
// Variables to store addresses of idiv and udiv functions within MCU ROM
unsigned int *pDivRom_idiv;
unsigned int *pDivRom_uidiv;
#endif

//*****************************************************************************
//
// Forward declaration of the default handlers. These are aliased.
// When the application defines a handler (with the same name), this will
// automatically take precedence over these weak definitions
//
//*****************************************************************************
     void ResetISR(void);
WEAK void NMI_Handler(void);
WEAK void HardFault_Handler(void);
WEAK void SVC_Handler(void);
WEAK void PendSV_Handler(void);
WEAK void SysTick_Handler(void);
WEAK void IntDefaultHandler(void);

//*****************************************************************************
//
// Forward declaration of the specific IRQ handlers. These are aliased
// to the IntDefaultHandler, which is a 'forever' loop. When the application
// defines a handler (with the same name), this will automatically take
// precedence over these weak definitions
//
//*****************************************************************************
void SPI0_IRQHandler(void)   ALIAS(IntDefaultHandler);
void DAC0_IRQHandler(void)   ALIAS(IntDefaultHandler);
void UART0_IRQHandler(void)   ALIAS(IntDefaultHandler);
void UART1_IRQHandler(void)   ALIAS(IntDefaultHandler);
void I2C1_IRQHandler(void)   ALIAS(IntDefaultHandler);
void I2C0_IRQHandler(void)   ALIAS(IntDefaultHandler);
void MRT_IRQHandler(void)   ALIAS(IntDefaultHandler);
void CMP_IRQHandler(void)   ALIAS(IntDefaultHandler);
void WDT_IRQHandler(void)   ALIAS(IntDefaultHandler);
void BOD_IRQHandler(void)   ALIAS(IntDefaultHandler);
void FLASH_IRQHandler(void)   ALIAS(IntDefaultHandler);
void WKT_IRQHandler(void)   ALIAS(IntDefaultHandler);
void ADC_SEQA_IRQHandler(void)   ALIAS(IntDefaultHandler);
void ADC_SEQB_IRQHandler(void)   ALIAS(IntDefaultHandler);
void ADC_THCMP_IRQHandler(void)   ALIAS(IntDefaultHandler);
void ADC_OVR_IRQHandler(void)   ALIAS(IntDefaultHandler);
void CTIMER0_IRQHandler(void)   ALIAS(IntDefaultHandler);
void PININT0_IRQHandler(void)   ALIAS(IntDefaultHandler);
void PININT1_IRQHandler(void)   ALIAS(IntDefaultHandler);
void PININT2_IRQHandler(void)   ALIAS(IntDefaultHandler);
void PININT3_IRQHandler(void)   ALIAS(IntDefaultHandler);
void PININT4_IRQHandler(void)   ALIAS(IntDefaultHandler);
void PININT5_IRQHandler(void)   ALIAS(IntDefaultHandler);
void PININT6_IRQHandler(void)   ALIAS(IntDefaultHandler);
void PININT7_IRQHandler(void)   ALIAS(IntDefaultHandler);

//*****************************************************************************
//
// The entry point for the application.
// __main() is the entry point for Redlib based applications
// main() is the entry point for Newlib based applications
//
//*****************************************************************************
#if defined (__REDLIB__)
extern void __main(void);
#else
extern int main(void);
#endif
//*****************************************************************************
//
// External declaration for the pointer to the stack top from the Linker Script
//
//*****************************************************************************
extern void _vStackTop(void);

//*****************************************************************************
//
// External declaration for LPC MCU vector table checksum from  Linker Script
//
//*****************************************************************************
WEAK extern void __valid_user_code_checksum();
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

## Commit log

2019-11-17 Add IMUCapture board step cad model, add prototye-version casing CAD model (this will be replaced to new later)
    [ARRAY_4x3.SLDASM, Housing.SLDPRT, Housing.STL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]
2019-11-17 Rename IMUCapture.step --> IMUTracker.step
    [IMUTracker.step]
2019-11-17 Rename Housing.SLDPRT --> IMUTracker_casing_v1.SLDPRT, add full assemble of QUIKS
    [AR-2622.ipt, Housing.SLDPRT, IMUTracker_casing_v1.SLDPRT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]
2019-11-17 add STL file for 3d printing, accordingly add & change directoriy
    [ARRAY_4x3.SLDASM, Housing.STL, IMUTracker_casing_v2.stl]
2019-11-18 Changed directory structure, remove appearance image
    [AR-2622.ipt, ARRAY_4x3.SLDASM, Housing.STL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]
2019-11-18 Update IMUTracker_assemble.iam according to the change of directory structure, add README into Hardware/IMUTracker, uplpad step cad model of full assemble.
    [IMUTracker_assemble.stp]
2019-11-18 Update .gitattributes
    ipt & iam are Inventor's file format. stl is 3d print data format, and step is a exchange format.
2019-11-19 Specified IMUTracker/Casing/ directory as binary. Update step cad file (maybe automatic backup save with clising this file last time)
2019-11-19 Add PCB design and CNC program.
    [IMUTrackerBase_8port_hub_pcb.dwg]
2019-11-19 Draw 3D model on Inventor, attached PA-4 cad model imported from JST website
    [B04B-PASK-1.STEP, IMUTrackerBase_8port_hub_asm.iam, IMUTrackerBase_8port_hub_pcb.ipt]
2019-11-19 WIP IMUTrackerBase
    [IMUTrackerBaseFrame.ipt]
2019-11-19 Designed 8-port hub board, add cnc milling data
    [B04B-PASK-1.STEP, IMUTrackerBase_8port_hub_asm.iam, IMUTrackerBase_8port_hub_pcb.dwg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]
2019-11-21 Modify IMUTrackerBase and base ASM, attach micro usb connector holder. Also add STL and STEP exchange format.
    [IMUTrackerBaseFrame.ipt, IMUTrackerBaseFrame.stl, IMUTrackerBase_8port_hub_asm.iam]
2019-11-21 Create separated dicectory onto Hardware/IMUTracker/Casing/ and add new design of Base
    [AR-2622.ipt, ARRAY_4x3.SLDASM, B04B-PASK-1.STEP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]
2019-11-21 Change directory stracture on Hardware/IMUTracker/Casing
    [AR-2622.ipt, ARRAY_4x3.SLDASM, B04B-PASK-1.STEP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]
2019-11-21 Erase duplicated files on previous commit
    [AR-2622.ipt, ARRAY_4x3.SLDASM, B04B-PASK-1.STEP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]
2020-01-01 Convert IMUTracker pcb 3d model from STEP to Inventor ipt/iam file, and group them onto IMUTracker_Inventor_model folder
    [Board_Geoms.iam, C10_C_0603_5C47C8CE.ipt, C11_C_0603_5C47C8DF.ipt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]
2020-01-01 Update assemble files regarding changes of IMUTracker PCB CAD model
    [C-2003-4.ipt, IMUTrackerBase_8port_hub_asm.iam, QUIKS_SINGLE_COVER.ipt]
2020-01-01 Add IMUTrackerBase as a directory reserved for binary files.
2020-01-01 Convert IMUTracker.step to Inventor CAD model and group them onto a new folder
    [Board_Geoms.iam, C10_C_0603_5C47C8CE.ipt, C11_C_0603_5C47C8DF.ipt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]
2020-01-01 Update regarding change of IMUTracker.step
    [C-2003-4.ipt, IMUTrackerBase_8port_hub_asm.iam, QUIKS_SINGLE_COVER.ipt]
2020-04-30 add IMUTracker paper
2020-05-22 complete IMUTracker paper
